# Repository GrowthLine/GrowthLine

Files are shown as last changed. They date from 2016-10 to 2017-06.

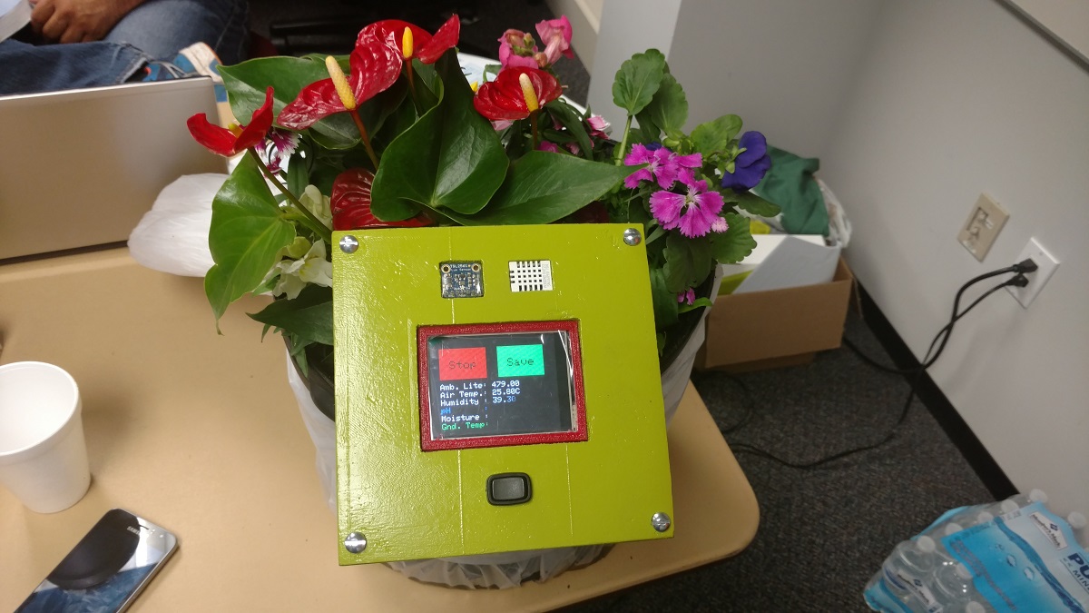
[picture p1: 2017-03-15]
web/img/testplant.jpg

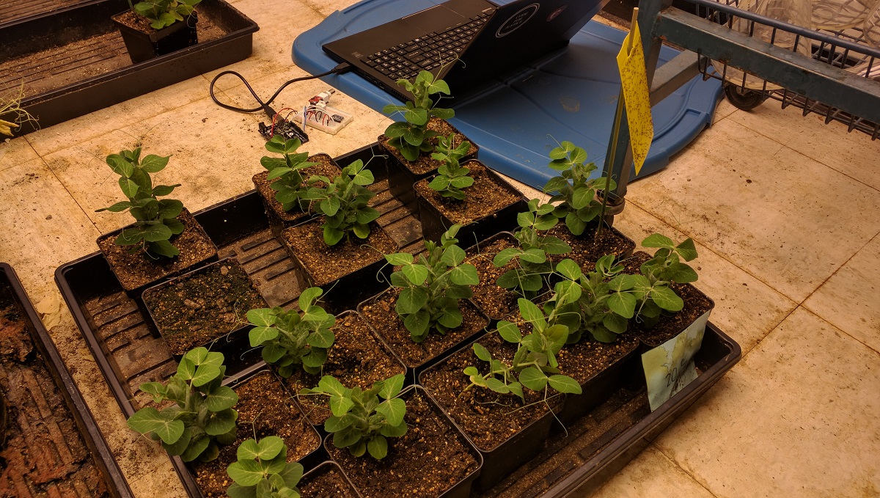
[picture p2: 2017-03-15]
web/img/data.jpg

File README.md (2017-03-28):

# GrowthLine
Growth Line Project

The GrowthLine directory contains the main code for the project itself. The TestFiles and Libraries directory contains test files and the libraries needed for the specific components used within the project.

Contributors: Henok Gezaw, Andrew Leverkuhn, Miguel Rosales, Jose Daniel Velazco, Daniel Weaver

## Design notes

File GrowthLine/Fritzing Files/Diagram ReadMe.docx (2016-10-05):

Diagram Information

- Created with Fritzing
  - Version 0.9.3b
  - Open source software that supports creation of electronics projects
  - Allows you to plan, document, and prepare project for production
  - Components for project are wired on a virtual breadboard
- Bread Board configuration
  - Centered around Arduino uno
  - The display(TFT Capacitive) and the lux sensor(TSL2561) both share serial clock(SCL) and serial data pins (SDA)
    - These two modules are communicated using the I²C (IIC) protocol
    - Multiple devices can be communicated to using only 2 pins
      - Varies based on micro controller
      - Analog pins 4 and 5 for Arduino uno
      - Each device has unique address to identify it in the line
    - I²C using series of rising and falling edges to signal
      - Start communication
      - End communication
      - Sending data to device
      - Read data from device
  - All modules share a common ground
  - The screen and lux sensor both use 3.3 volts
  - The remaining modules use 5v
  - There are 3 digital pins and 4 analog pins not being used
    - Possible future expansion
  - pH module (pH circuit) uses 2 pins
    - digital pins 3 and 4
    - can operate in I²C mode to allow for future expansion
    - isolation board not shown in this model (doesn’t affect wiring)
  - Air temperature and humidity (DHT11)
    - Uses 1 pin to transmit data for both readings
    - Digital pin 5
  - Display (TFT capactive)
    - Digital pins 9-13 for display control
    - Digital pin 4 to control the sdcard
    - Analog pins 4 and 5 used to read touch screen
      - SDA and SCL
  - Lux sensor (TSL2561)
    - Analog pins 4 and 5
      - SDA and SCL
  - Soil moisture and temperature (SHT10)
    - Digital pin 6 for data
    - Digital pin 7 for clock (bit that powers the logic)
  - Wiring has to be done manually at this stage
- Schematic
  - Simplifies the connection by merging
    - Common grounds
    - Common power lines
    - Removing the breadboard for direct connections
  - Same info as above (breadboard layout)
  - Modules represented by bloacks
  - Connections represented by a solid black line or a colored dashed line
  - Wiring automated by fritzing
- PCB (optional)
  - Fritzing can generate a PCB design based on your wiring
  - Design can be sent to fabricator for manufacturing
  - Wiring is automated by fritzing

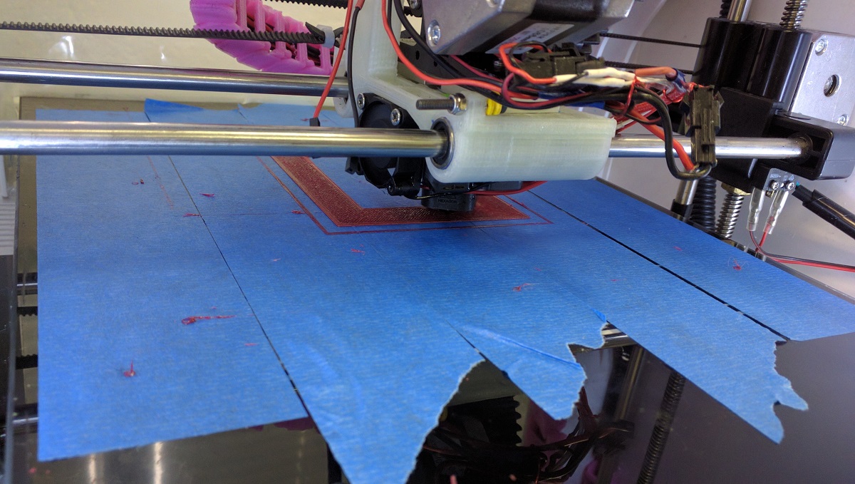
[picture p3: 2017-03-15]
web/img/3DPrint.jpg

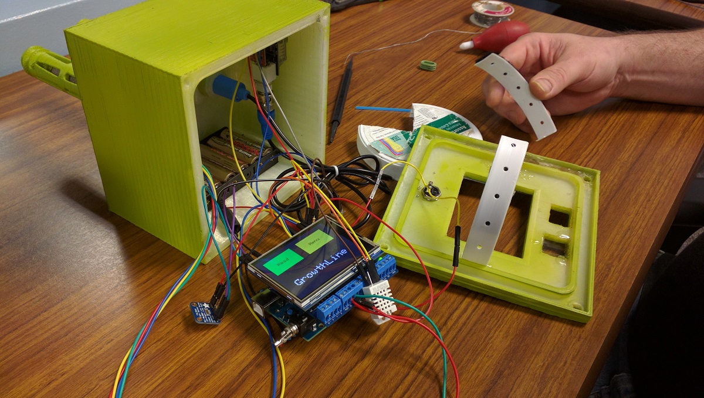
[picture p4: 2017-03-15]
web/img/Inside.jpg

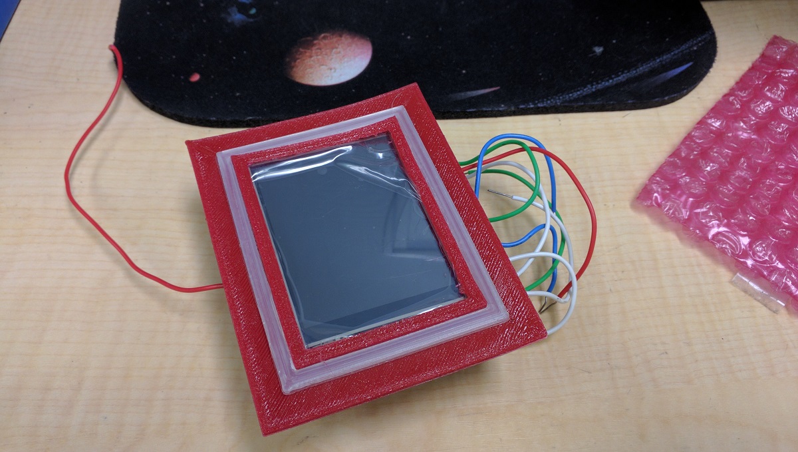
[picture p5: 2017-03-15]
web/img/Gasket.jpg

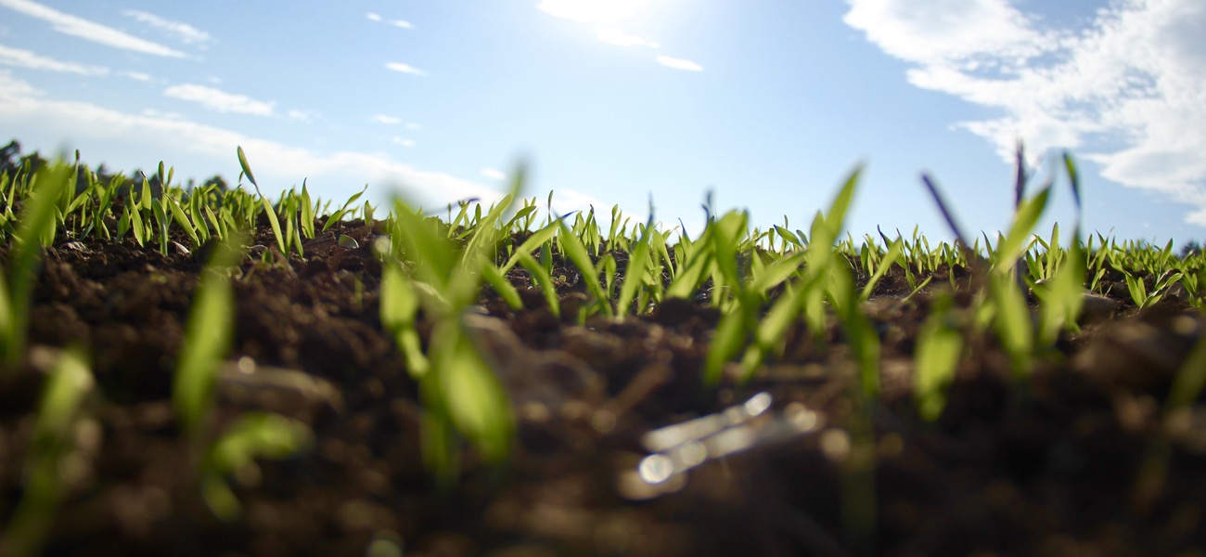
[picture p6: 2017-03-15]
web/img/growth.jpg

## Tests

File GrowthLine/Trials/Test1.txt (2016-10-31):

Reading 1

Setup is complete
The lux is: 11074.00
The air temperature is: 25.30
The humidity is: 47.90
The pH is: 2.32

The lux is: 11024.00
The air temperature is: 25.40
The humidity is: 46.60
The pH is: 2.09

The lux is: 11055.00
The air temperature is: 25.50
The humidity is: 46.20
The pH is: 0.00

The lux is: 11272.00
The air temperature is: 25.60
The humidity is: 45.90
The pH is: 1.91

The lux is: 11295.00
The air temperature is: 25.60
The humidity is: 46.00
The pH is: 1.70

The lux is: 11402.00
The air temperature is: 25.60
The humidity is: 46.00
The pH is: 1.47

The lux is: 11257.00
The air temperature is: 25.70
The humidity is: 45.70
The pH is: 1.25

The lux is: 11433.00
The air temperature is: 25.80
The humidity is: 45.40
The pH is: 1.02

The lux is: 11438.00
The air temperature is: 25.80
The humidity is: 45.20
The pH is: 0.85

The lux is: 11464.00
The air temperature is: 25.90
The humidity is: 45.10
The pH is: 0.00

The lux is: 11472.00
The air temperature is: 25.90
The humidity is: 44.80
The pH is: 0.69

The lux is: 11410.00
The air temperature is: 26.00
The humidity is: 44.70
The pH is: 0.47

The lux is: 11415.00
The air temperature is: 26.00
The humidity is: 44.60
The pH is: 0.25

The lux is: 11466.00
The air temperature is: 26.00
The humidity is: 44.40
The pH is: 0.00

The lux is: 11473.00
The air temperature is: 26.10
The humidity is: 44.30
The pH is: 0.00

The lux is: 11425.00
The air temperature is: 26.10
The humidity is: 44.30
The pH is: 0.00

The lux is: 11476.00
The air temperature is: 26.20
The humidity is: 44.20
The pH is: 0.00

The lux is: 11490.00
The air temperature is: 26.20
The humidity is: 44.10
The pH is: 0.00

The lux is: 11481.00
The air temperature is: 26.30
The humidity is: 43.90
The pH is: 0.00

The lux is: 11477.00
The air temperature is: 26.30
The humidity is: 43.90
The pH is: 0.00

The lux is: 11497.00
The air temperature is: 26.30
The humidity is: 43.80
The pH is: 0.00

The lux is: 11489.00
The air temperature is: 26.40
The humidity is: 43.70
The pH is: 0.00

The lux is: 11474.00
The air temperature is: 26.50
The humidity is: 43.50
The pH is: 0.00

The lux is: 11485.00
The air temperature is: 26.50
The humidity is: 43.30
The pH is: 0.00

The lux is: 11244.00
The air temperature is: 26.50
The humidity is: 43.20
The pH is: 0.00

The lux is: 11227.00
The air temperature is: 26.60
The humidity is: 43.20
The pH is: 0.00

The lux is: 11449.00
The air temperature is: 26.70
The humidity is: 43.10
The pH is: 0.00

The lux is: 11453.00
The air temperature is: 26.70
The humidity is: 43.00
The pH is: 0.00

The lux is: 11448.00
The air temperature is: 26.70
The humidity is: 43.20
The pH is: 0.00

The lux is: 11431.00
The air temperature is: 26.70
The humidity is: 43.10
The pH is: 0.00

The lux is: 11411.00
The air temperature is: 26.80
The humidity is: 43.00
The pH is: 0.00

The lux is: 11415.00
The air temperature is: 26.90
The humidity is: 42.70
The pH is: 0.00

The lux is: 11455.00
The air temperature is: 26.90
The humidity is: 42.50
The pH is: 0.00

The lux is: 11441.00
The air temperature is: 27.00
The humidity is: 42.30
The pH is: 0.00

The lux is: 11450.00
The air temperature is: 27.00
The humidity is: 42.20
The pH is: 0.00

The lux is: 11441.00
The air temperature is: 27.00
The humidity is: 42.10
The pH is: 0.00

The lux is: 11436.00
The air temperature is: 27.10
The humidity is: 41.90
The pH is: 0.00

The lux is: 11441.00
The air temperature is: 27.10
The humidity is: 42.00
The pH is: 0.00

The lux is: 11439.00
The air temperature is: 27.20
The humidity is: 41.80
The pH is: 0.00

The lux is: 11375.00
The air temperature is: 27.20
The humidity is: 41.70
The pH is: 0.00

The lux is: 11424.00
The air temperature is: 27.20
The humidity is: 41.60
The pH is: 0.00

The lux is: 11151.00
The air temperature is: 27.30
The humidity is: 41.50
The pH is: 0.00

The lux is: 11203.00
The air temperature is: 27.30
The humidity is: 41.40
The pH is: 0.00

The lux is: 11229.00
The air temperature is: 27.30
The humidity is: 41.50
The pH is: 0.00

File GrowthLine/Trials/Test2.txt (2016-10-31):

Reading 2 - More Inside

Setup is complete
The lux is: 11946.00
The air temperature is: 28.20
The humidity is: 39.70
The pH is: 0.00

The lux is: 12041.00
The air temperature is: 28.70
The humidity is: 38.40
The pH is: 0.00

The lux is: 12074.00
The air temperature is: 28.70
The humidity is: 38.30
The pH is: 0.00

The lux is: 12079.00
The air temperature is: 28.60
The humidity is: 38.20
The pH is: 0.00

The lux is: 12077.00
The air temperature is: 28.70
The humidity is: 38.10
The pH is: 0.00

The lux is: 12061.00
The air temperature is: 28.70
The humidity is: 38.00
The pH is: 0.00

The lux is: 12096.00
The air temperature is: 28.70
The humidity is: 38.00
The pH is: 0.00

The lux is: 12096.00
The air temperature is: 28.80
The humidity is: 38.00
The pH is: 0.00

The lux is: 12103.00
The air temperature is: 28.80
The humidity is: 38.00
The pH is: 0.00

The lux is: 12088.00
The air temperature is: 28.80
The humidity is: 38.10
The pH is: 0.00

The lux is: 12107.00
The air temperature is: 28.80
The humidity is: 38.00
The pH is: 0.00

The lux is: 12102.00
The air temperature is: 28.80
The humidity is: 37.90
The pH is: 0.00

The lux is: 12102.00
The air temperature is: 28.90
The humidity is: 37.90
The pH is: 0.00

The lux is: 12103.00
The air temperature is: 28.90
The humidity is: 37.80
The pH is: 0.00

The lux is: 12106.00
The air temperature is: 28.90
The humidity is: 37.80
The pH is: 0.00

The lux is: 12118.00
The air temperature is: 28.90
The humidity is: 37.80
The pH is: 0.00

The lux is: 12099.00
The air temperature is: 29.00
The humidity is: 37.80
The pH is: 0.00

The lux is: 12073.00
The air temperature is: 28.90
The humidity is: 37.80
The pH is: 0.00

The lux is: 12096.00
The air temperature is: 29.00
The humidity is: 37.80
The pH is: 0.00

The lux is: 12109.00
The air temperature is: 29.00
The humidity is: 37.80
The pH is: 0.00

The lux is: 12117.00
The air temperature is: 29.00
The humidity is: 37.80
The pH is: 0.00

The lux is: 12054.00
The air temperature is: 29.10
The humidity is: 37.70
The pH is: 0.00

The lux is: 12117.00
The air temperature is: 29.10
The humidity is: 37.70
The pH is: 0.00

The lux is: 12117.00
The air temperature is: 29.10
The humidity is: 37.60
The pH is: 0.00

The lux is: 12094.00
The air temperature is: 29.10
The humidity is: 37.50
The pH is: 0.00

The lux is: 12094.00
The air temperature is: 29.20
The humidity is: 37.30
The pH is: 0.00

The lux is: 12127.00
The air temperature is: 29.20
The humidity is: 37.30
The pH is: 0.00

The lux is: 12133.00
The air temperature is: 29.20
The humidity is: 37.30
The pH is: 0.00

The lux is: 12111.00
The air temperature is: 29.20
The humidity is: 37.20
The pH is: 0.00

The lux is: 12111.00
The air temperature is: 29.20
The humidity is: 37.10
The pH is: 0.00

The lux is: 12112.00
The air temperature is: 29.30
The humidity is: 37.10
The pH is: 0.00

The lux is: 12110.00
The air temperature is: 29.30
The humidity is: 37.20
The pH is: 0.00

The lux is: 12134.00
The air temperature is: 29.30
The humidity is: 37.20
The pH is: 0.00

The lux is: 12140.00
The air temperature is: 29.30
The humidity is: 37.10
The pH is: 0.00

The lux is: 12138.00
The air temperature is: 29.30
The humidity is: 37.20
The pH is: 0.00

The lux is: 12140.00
The air temperature is: 29.30
The humidity is: 37.20
The pH is: 0.00

The lux is: 12137.00
The air temperature is: 29.30
The humidity is: 37.10
The pH is: 0.00

The lux is: 12126.00
The air temperature is: 29.30
The humidity is: 37.00
The pH is: 0.00

The lux is: 12126.00
The air temperature is: 29.40
The humidity is: 37.00
The pH is: 0.00

The lux is: 12092.00
The air temperature is: 29.40
The humidity is: 37.00
The pH is: 0.00

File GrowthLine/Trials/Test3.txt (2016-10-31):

Reading 3 - Inside plant box

Setup is complete
The lux is: 12002.00
The air temperature is: 29.50
The humidity is: 36.60
The pH is: 0.00

The lux is: 10934.00
The air temperature is: 29.50
The humidity is: 36.60
The pH is: 0.00

The lux is: 11041.00
The air temperature is: 29.50
The humidity is: 37.70
The pH is: 0.00

The lux is: 11237.00
The air temperature is: 29.50
The humidity is: 37.30
The pH is: 0.00

The lux is: 11248.00
The air temperature is: 29.50
The humidity is: 37.00
The pH is: 0.00

The lux is: 11215.00
The air temperature is: 29.50
The humidity is: 36.70
The pH is: 0.00

The lux is: 11215.00
The air temperature is: 29.50
The humidity is: 36.70
The pH is: 0.00

The lux is: 11213.00
The air temperature is: 29.50
The humidity is: 36.70
The pH is: 0.00

The lux is: 11216.00
The air temperature is: 29.50
The humidity is: 36.60
The pH is: 0.00

The lux is: 11233.00
The air temperature is: 29.50
The humidity is: 36.80
The pH is: 0.00

The lux is: 11228.00
The air temperature is: 29.50
The humidity is: 36.90
The pH is: 0.00

The lux is: 11210.00
The air temperature is: 29.50
The humidity is: 36.80
The pH is: 0.00

The lux is: 11210.00
The air temperature is: 29.50
The humidity is: 36.80
The pH is: 0.00

The lux is: 11162.00
The air temperature is: 29.50
The humidity is: 36.70
The pH is: 0.00

The lux is: 11198.00
The air temperature is: 29.40
The humidity is: 36.70
The pH is: 0.00

The lux is: 11122.00
The air temperature is: 29.40
The humidity is: 36.80
The pH is: 0.00

The lux is: 11122.00
The air temperature is: 29.40
The humidity is: 36.90
The pH is: 0.00

The lux is: 11116.00
The air temperature is: 29.40
The humidity is: 36.80
The pH is: 0.00

The lux is: 11111.00
The air temperature is: 29.40
The humidity is: 36.60
The pH is: 0.00

The lux is: 11116.00
The air temperature is: 29.40
The humidity is: 36.50
The pH is: 0.00

The lux is: 11219.00
The air temperature is: 29.40
The humidity is: 36.50
The pH is: 0.00

The lux is: 11172.00
The air temperature is: 29.40
The humidity is: 36.50
The pH is: 0.00

The lux is: 11253.00
The air temperature is: 29.40
The humidity is: 36.70
The pH is: 0.00

The lux is: 11260.00
The air temperature is: 29.40
The humidity is: 36.70
The pH is: 0.00

The lux is: 11254.00
The air temperature is: 29.40
The humidity is: 36.70
The pH is: 0.00

The lux is: 11249.00
The air temperature is: 29.40
The humidity is: 36.80
The pH is: 0.00

The lux is: 11246.00
The air temperature is: 29.40
The humidity is: 36.80
The pH is: 0.00

The lux is: 11246.00
The air temperature is: 29.40
The humidity is: 36.90
The pH is: 0.00

The lux is: 11242.00
The air temperature is: 29.40
The humidity is: 36.90
The pH is: 0.00

The lux is: 11235.00
The air temperature is: 29.40
The humidity is: 36.90
The pH is: 0.00

The lux is: 11227.00
The air temperature is: 29.40
The humidity is: 36.80
The pH is: 0.00

The lux is: 11222.00
The air temperature is: 29.40
The humidity is: 36.90
The pH is: 0.00

The lux is: 11219.00
The air temperature is: 29.40
The humidity is: 37.10
The pH is: 0.00

The lux is: 11218.00
The air temperature is: 29.40
The humidity is: 37.00
The pH is: 0.00

The lux is: 11222.00
The air temperature is: 29.30
The humidity is: 36.90
The pH is: 0.00

The lux is: 11224.00
The air temperature is: 29.40
The humidity is: 36.80
The pH is: 0.00

The lux is: 11227.00
The air temperature is: 29.30
The humidity is: 37.00
The pH is: 0.00

The lux is: 11230.00
The air temperature is: 29.30
The humidity is: 37.00
The pH is: 0.00

The lux is: 11229.00
The air temperature is: 29.30
The humidity is: 36.90
The pH is: 0.00

The lux is: 11206.00
The air temperature is: 29.30
The humidity is: 36.90
The pH is: 0.00

The lux is: 11210.00
The air temperature is: 29.30
The humidity is: 36.90
The pH is: 0.00

The lux is: 11209.00
The air temperature is: 29.30
The humidity is: 36.90
The pH is: 0.00

The lux is: 11232.00
The air temperature is: 29.30
The humidity is: 37.00
The pH is: 0.00

The lux is: 11229.00
The air temperature is: 29.30
The humidity is: 37.00
The pH is: 0.00

The lux is: 11196.00
The air temperature is: 29.30
The humidity is: 37.00
The pH is: 0.00

The lux is: 11220.00
The air temperature is: 29.30
The humidity is: 36.90
The pH is: 0.00

The lux is: 11210.00
The air temperature is: 29.30
The humidity is: 36.90
The pH is: 0.00

The lux is: 10985.00
The air temperature is: 29.30
The humidity is: 37.00
The pH is: 0.00

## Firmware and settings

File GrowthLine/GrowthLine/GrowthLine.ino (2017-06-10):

#include "lib.h"

/* Variable Declarations */
List<Reading> readings(5);           // List used to hold reading objects. Structured in a queue.
Sensors sensors;                                // Object that will hold and manage all other sensors
int deviceState;                                // State of device
bool fahrenheit;                                // Saves user information about temperature unit
bool redraw;                                    // Flag used to know when to redraw a screen
bool tempChange;                                // Flag used to ID when to redraw Temp buttons
unsigned long milliseconds;                     // saves milliseconds. Used with millis() to check lenths of time
unsigned int currentRead;                       // holds a value of the latest read displayed on the log screen
String statusBar;                               // holds the message displayed on the status bar
Adafruit_STMPE610 *ts;                          // pointer to a touch screen object
Adafruit_ILI9341 *tft;                          // pointer to a display object
int tempReadingNumber;
Reading tempReading;

void setup() {
  Serial.begin(9600);
  Serial.println("Software Initializing");
  tft = new Adafruit_ILI9341(TFT_CS, TFT_DC);
  tft->begin();
  tft->setRotation(1);
  draw_Startup();
  deviceState   = READY_STATE;
  redraw        = true;
  fahrenheit    = false;
  tempChange    = true;
  currentRead   = 1;
  statusBar     = "GrowthLine";
  String logNumberBuffer = "";                     // holds the settings from the buffer
  String lineReadBuffer = "";

  /* Add the sensors to our Sensors object */
  LightSensor* lightSensor = new LightSensor();
  sensors.addSensor(lightSensor);
  TempHumid* tempHumid = new TempHumid(TEMP_HUMID_PIN);
  sensors.addSensor(tempHumid);
  pH* ph = new pH(PH_RECEIVE_PIN, PH_TRANSMIT_PIN);
  sensors.addSensor(ph);
  TempMoist* tempMoist = new TempMoist(TEMP_MOIST_DATA_PIN, TEMP_MOIST_CLOCK_PIN);
  sensors.addSensor(tempMoist);

  /* Create our touch objects */
  ts = new Adafruit_STMPE610(STMPE_CS);

  /* Setup the sensors */
  sensors.setupSensors();

  /* Setting up the SD card */
  if (! SD.begin(SD_CS_PIN)) {
    Serial.println("SD card initialization failed!");
  }
  else {
    Logger::saveEnable = false;
    // If the settings file is missing, make it with the defaults
    if ( !SD.exists("settings.txt")) {
      Serial.println("Making Settings File");
      File settingsFile = SD.open("settings.txt", FILE_WRITE);
      settingsFile.println("TempUnit=C");
      settingsFile.println("LogFile=1");
      settingsFile.println("Reading=1");
      settingsFile.close();
    }
    File settingsFile = SD.open("settings.txt");
    while (settingsFile.available() && (char)settingsFile.read() != '=');               // find the first = sign, which indicates temp. unit
    if (settingsFile.available() && (char)settingsFile.read() == 'F')
      fahrenheit = true;
    while (settingsFile.available() && (char)settingsFile.read() != '=');
    while (settingsFile.available() && (char)settingsFile.peek() != '\n') {
      logNumberBuffer += (char)settingsFile.read();
    }
    while (settingsFile.available() && (char)settingsFile.read() != '=');
    while (settingsFile.available() && (char)settingsFile.peek() != '\n') {
      lineReadBuffer += (char)settingsFile.read();
    }
    if (logNumberBuffer.toInt() != 0) {
      Logger::logFileNumber = logNumberBuffer.toInt();
    }
    else {
      Logger::logFileNumber = 1;
    }
    if (lineReadBuffer.toInt() != 0) {
      Logger::readingNumber = lineReadBuffer.toInt();
    }
    else {
      Logger::readingNumber = 1;
    }
    settingsFile.close();
    Logger::checkLogExists();
  }
  /* check that touch screen is started propperly */
  while (true) {
    if (ts->begin()) {
      break;
    } else {
      Serial.println("Touchscreen controller start failure!");
    }
  }
  Serial.println("Setup is complete");
}

/*
   The if (redraw) prevents the entire screen from
   being redrawn every loop() cycle. This prevents
   flickering.
*/
void loop() {
  // Determine if the screen was touched and on which quadrant
  TS_Point touchedPoint;
  uint8_t touchedQuadrant = BTN_NONE;
  while (ts->touched()) {
    touchedPoint = ts->getPoint();
    if ( touchedPoint.z < 75 )
      touchedQuadrant = getQuadrantFromPoint(&touchedPoint);
  }

  // State Machine of the device
  switch (deviceState) {
    case READY_STATE:
      if (redraw) {
        Serial.println("device is ready");
        draw_MainMenu();
        redraw = false;
      }
      switch (touchedQuadrant) {
        case BTN_NE:
          deviceState = MENU_STATE;
          redraw = true;
          break;
        case BTN_NW:
          deviceState = WARMUP_STATE;
          redraw = true;
          break;
      }
      break;
    case WARMUP_STATE:
      if (redraw) {
        draw_WarmUpScreen();
        redraw = false;
      }
      milliseconds = millis();
      for ( int i = 0; i < 5; i++ ) {                       // get initial 5 readings
        readings.add( sensors.getReading() );
        while (millis() - milliseconds < READING_FREQUENCY);
        milliseconds = millis();
      }

      while (!stableReadings(readings)) {
        milliseconds = millis();
        while ( millis() - milliseconds < READING_FREQUENCY);
        readings.add( sensors.getReading() );
      }
      deviceState = READ_STATE;
      redraw = true;
      break;
    case READ_STATE:
      if (redraw) {
        draw_ReadScreen();
        redraw = false;
      }
      switch (touchedQuadrant) {
        case BTN_NE:
          if (Logger::saveEnable) {             // if save button is pressed, save and go back to main menu
            deviceState = SAVE_STATE;
            redraw = true;
          }
          break;
        case BTN_NW:                   // if stop button is pressed, do not save and go back to main menu
          deviceState = READY_STATE;
          redraw = true;
          statusBar = "GrowthLine";
          readings.clear();
          break;
      }
      if ( millis() - milliseconds > READING_FREQUENCY) {   // updates displayed reading
        readings.add( sensors.getReading() );
        milliseconds = millis();
        update_Readings();
      }
      break;
    case SAVE_STATE:
      if (redraw) {
        draw_SaveScreen();
        redraw = false;
      }
      Serial.println("Saving log file");
      tempReading = readings.get_new();
      Logger::saveLog(tempReading, fahrenheit);
      Serial.println("Log saved");
      deviceState = READY_STATE;
      redraw = true;
      statusBar = "Read Saved";
      readings.clear();
      Logger::saveSettings(fahrenheit);
      Serial.println("Entering READY_STATE");
      break;
    case MENU_STATE:
      if (redraw) {
        draw_MenuScreen();
        redraw = false;
      }
      switch (touchedQuadrant) {
        case BTN_NE:
          deviceState = SETTINGS_STATE;
          redraw = true;
          break;
        case BTN_NW:
          deviceState = READY_STATE;
          redraw = true;
          statusBar = "GrowthLine";
          break;
        case BTN_SW:
          if ( Logger::saveEnable ) {
            deviceState = LOG_STATE;
            redraw = true;
          }
          break;
        case BTN_SE:
          deviceState = SHUTDOWN_STATE;
          redraw = true;
          break;
      }
      break;
    case SETTINGS_STATE:
      if (redraw) {
        draw_SettingsScreen();
        redraw = false;
      }
      if (tempChange) {
        draw_TempButtons();
        tempChange = false;
      }
      switch (touchedQuadrant) {
        case BTN_NE:
          if ( fahrenheit ) {
            fahrenheit = false;
          } else {
            fahrenheit = true;
          }
          Logger::saveSettings(fahrenheit);
          tempChange = true;
          break;
        case BTN_NW:
          deviceState = MENU_STATE;
          redraw = true;
          break;
        case BTN_SW:
          deviceState = CALIBRATE_STATE;
          redraw = true;
          break;
        case BTN_SE:
          if (Logger::saveEnable) {
            Logger::logFileNumber += 1;
            Logger::checkLogExists();
            Logger::readingNumber = 1;
            Logger::saveSettings(fahrenheit);
            deviceState = READY_STATE;
            redraw = true;
            statusBar = "NewLogFile";
          }
          break;
      }
      break;
    case CALIBRATE_STATE:
      if (redraw) {
        draw_CalibrateScreen();
        redraw = false;
      }
      if (touchedQuadrant == BTN_NW) {                      // if stop button is pressed, do not save and go back to menu
        deviceState = MENU_STATE;
        redraw = true;
      }
      else if ( touchedQuadrant == BTN_NE) {                // if go button is pressed, calibrate pH sensor
        pH* phSensor = (pH*)sensors.getSensor(PH_SENSOR_ID);
        phSensor->calibrate();
        deviceState = READY_STATE;
        redraw = true;
        statusBar = "Calibrated";
      }
      break;
    case LOG_STATE:
      if (redraw) {
        String logs[5] = {"", "", "", "", ""};
        Logger::getLogs(String("log") + Logger::logFileNumber + ".txt", logs, &currentRead);
        draw_LogScreen(logs);
        redraw = false;
      }
      if ( touchedQuadrant == BTN_NW) {
        deviceState = MENU_STATE;
        currentRead = 1;
        redraw = true;
      }
      else if ( touchedQuadrant == BTN_NE) {
        String logs[5] = {"", "", "", "", ""};
        Logger::getLogs(String("log") + Logger::logFileNumber + ".txt", logs, &currentRead);
        update_Logs(logs);
        if (currentRead >= Logger::readingNumber)
          currentRead = 1;
      }
      break;
    case SHUTDOWN_STATE:      // ******** Need to do this one ******* ///
      if (redraw) {
        draw_ShutdownScreen();
        redraw = false;
      }
      break;
    default:
      break;
  }
}

/* Display Functions */
void draw_MainMenu() {
  // Blank screen
  tft->fillScreen(ILI9341_BLACK);

  /* Set text attributes */
  tft->setTextSize(2);

  /* Draw NW 'Read' button */
  tft->fillRect( 20, 20, 120, 80, ILI9341_GREEN );
  tft->setCursor( 55, 52);
  tft->setTextColor( ILI9341_BLACK, ILI9341_GREEN );
  tft->println("Read");

  /* Draw NE 'Menu' button */
  tft->fillRect(170, 20, 120, 80, ILI9341_YELLOW);
  tft->setCursor(205, 52);
  tft->setTextColor( ILI9341_BLACK, ILI9341_YELLOW);
  tft->println("Menu");

  /* Draw 'GrowthLine' text logo */
  tft->setTextSize(4);
  tft->setTextColor( ILI9341_WHITE, ILI9341_BLACK);
  tft->setCursor(35, 162);
  tft->println(statusBar);
}

void draw_WarmUpScreen() {
  /* Blank screen */
  tft->fillScreen(ILI9341_BLACK);

  /* Set text attributes and draw text */
  tft->setTextSize(3);
  tft->setCursor( 70, 100);
  tft->setTextColor( ILI9341_WHITE, ILI9341_BLACK);
  tft->println("Warming up");
}

void draw_SaveScreen() {
  /* Blank screen */
  tft->fillScreen(ILI9341_BLACK);

  /* Set text attributes and draw text. */
  tft->setTextSize(3);
  tft->setCursor( 82, 100);
  tft->setTextColor( ILI9341_WHITE, ILI9341_BLACK);
  tft->println("Saving");
}

void draw_Startup() {
  /* Blank screen */
  tft->fillScreen(ILI9341_BLACK);

  /* Set text attributes and draw text. */
  tft->setTextSize(3);
  tft->setCursor( 30, 100);
  tft->setTextColor( ILI9341_WHITE, ILI9341_BLACK);
  tft->println("  Initializing  ");
}

void draw_ShutdownScreen() {
  /* Blank screen */
  tft->fillScreen(ILI9341_BLACK);

  /* Set text attributes and draw text. */
  tft->setTextSize(3);
  tft->setCursor( 30, 100);
  tft->setTextColor( ILI9341_WHITE, ILI9341_BLACK);
  tft->println("Safe to Shutdown");
}

void draw_ReadScreen() {
  // Blank the screen
  tft->fillScreen(ILI9341_BLACK);

  // Set text parameters
  tft->setTextSize(3);

  // Draw NW 'Stop' button
  tft->fillRect( 20, 20, 120, 80, ILI9341_RED);
  tft->setCursor( 45, 52);
  tft->setTextColor( ILI9341_BLACK, ILI9341_RED);
  tft->println("Stop");

  // Draw NE 'Save' button
  tft->fillRect(170, 20, 120, 80, ILI9341_GREEN);
  tft->setCursor(195, 52);
  tft->setTextColor( ILI9341_BLACK, ILI9341_GREEN);
  tft->println("Save");
}

void update_Readings() {
  /* Blank out numbers */
  tft->fillRect(140, 101, 180, 139, ILI9341_BLACK);

  /* Set text parameters */
  tft->setTextSize(2);
  tft->setTextColor( ILI9341_WHITE, ILI9341_BLACK);

  /* Draw reading 1 - Ambient Light */
  String amb_lite    = "Amb. Lite: ";
  tft->setCursor( 20, 112);
  tft->println(amb_lite + readings.get_new().getReadValueByType(ReadType::LUX));

  /* Draw reading 2 - Air Temperature */
  String air_temp    = "Air Temp.: ";
  tft->setCursor( 20, 132);
  if (fahrenheit) {
    tft->println(air_temp + cToF(readings.get_new().getReadValueByType(ReadType::AIR_TEMP)) + "F");
  } else {
    tft->println(air_temp + readings.get_new().getReadValueByType(ReadType::AIR_TEMP) + "C");
  }

  /* Draw reading 3 - Humidity */
  String humidity    = "Humidity : ";
  tft->setCursor( 20, 152);
  tft->println(humidity + readings.get_new().getReadValueByType(ReadType::HUMIDITY));

  /* Draw reading 4 - Soil pH */
  switch (phStatus(readings.get_new().getReadValueByType(ReadType::PH))) {
    case BAD_LOW:
      tft->setTextColor( ILI9341_BLUE, ILI9341_BLACK);
      break;
    case GOOD:
      tft->setTextColor( ILI9341_GREEN, ILI9341_BLACK);
      break;
    case BAD_HIGH:
      tft->setTextColor( ILI9341_RED, ILI9341_BLACK);
      break;
    default:
      break;
  }
  String ph          = "pH       : ";
  tft->setCursor( 20, 172);
  tft->println(ph + readings.get_new().getReadValueByType(ReadType::PH));

  /* Draw reading 5 - Soil moisture  */
  tft->setTextColor( ILI9341_WHITE, ILI9341_BLACK);
  String moisture    = "Moisture : ";
  tft->setCursor( 20, 192);
  tft->println(moisture + readings.get_new().getReadValueByType(ReadType::MOISTURE));

  /* Draw rea
    ding 6 - Ground temperature */
  switch (groundTempStatus(readings.get_new().getReadValueByType(ReadType::GROUND_TEMP))) {
    case BAD_LOW:
      tft->setTextColor( ILI9341_BLUE, ILI9341_BLACK);
      break;
    case GOOD:
      tft->setTextColor( ILI9341_GREEN, ILI9341_BLACK);
      break;
    case BAD_HIGH:
      tft->setTextColor( ILI9341_RED, ILI9341_BLACK);
      break;
    default:
      break;
  }
  String ground_temp = "Gnd. Temp: ";
  tft->setCursor( 20, 212);
  if (fahrenheit) {
    tft->println(ground_temp + cToF(readings.get_new().getReadValueByType(ReadType::GROUND_TEMP)) + "F");
  } else {
    tft->println(ground_temp + readings.get_new().getReadValueByType(ReadType::GROUND_TEMP) + "C");
  }
}

void draw_CalibrateScreen() {
  /* Blank the screen */
  tft->fillScreen(ILI9341_BLACK);

  /* Set text attributes */
  tft->setTextSize(3);

  /* Draw NW 'Back' button */
  tft->fillRect( 20, 20, 120, 80, ILI9341_RED);
  tft->setCursor( 45, 52);
  tft->setTextColor( ILI9341_BLACK, ILI9341_RED);
  tft->println("Back");

  /* Draw NE 'Go' button */
  tft->fillRect(170, 20, 120, 80, ILI9341_GREEN);
  tft->setCursor(215, 52);
  tft->setTextColor( ILI9341_BLACK, ILI9341_GREEN);
  tft->println("Go");

  /* Set text attributes and draw instructions */
  tft->setTextSize(2);
  tft->setTextColor( ILI9341_WHITE, ILI9341_BLACK);
  tft->setCursor( 20, 132); tft->print("Dip the pH probe into a");
  tft->setCursor( 20, 152); tft->print(" 7 pH solution at 25C." );
  tft->setCursor( 20, 172); tft->print(" After 2 min, press Go.");
  tft->setCursor( 20, 212); tft->print(" Press back to cancel." );
}

void draw_MenuScreen() {
  /* Blank screen */
  tft->fillScreen(ILI9341_BLACK);

  /* Set text attributes */
  tft->setTextSize(2);
  tft->setTextColor( ILI9341_BLACK, ILI9341_YELLOW );

  /* Draw NW 'Back' button */
  tft->fillRect( 20, 20, 120, 80, ILI9341_YELLOW );
  tft->setCursor( 55, 52);
  tft->println("Back");

  /* Draw NE 'Settings' button */
  tft->fillRect(180, 20, 120, 80, ILI9341_YELLOW);
  tft->setCursor(193, 52);
  tft->println("Settings");

  /* Set text color for following buttons */
  tft->setTextColor( ILI9341_BLACK, ILI9341_MAGENTA);

  /* Draw SW 'View Logs' button */
  tft->fillRect( 20, 140, 120, 80, ILI9341_MAGENTA);
  tft->setCursor( 25, 172);
  tft->println("View Logs");

  /* Draw SE 'Shut Down' button */
  tft->fillRect(180, 140, 120, 80, ILI9341_MAGENTA);
  tft->setCursor(185, 172);
  tft->println("Shut Down");
}

void draw_SettingsScreen() {
  tft->fillScreen(ILI9341_BLACK);
  // Draw boxes
  tft->fillRect( 20, 20, 120, 80, ILI9341_YELLOW );
  tft->fillRect( 20, 140, 120, 80, ILI9341_MAGENTA);
  tft->fillRect(180, 140, 120, 80, ILI9341_MAGENTA);
  tft->setTextSize(2);
  // Write text on button 1
  tft->setCursor( 55, 52);
  tft->setTextColor( ILI9341_BLACK, ILI9341_YELLOW );
  tft->println("Back");
  draw_TempButtons();
  // Set text color for following buttons
  tft->setTextColor( ILI9341_BLACK, ILI9341_MAGENTA);
  // Write text on button 3
  tft->setCursor( 27, 172);
  tft->println("Calibrate");
  // Write text on button 4
  tft->setCursor(200, 172);
  tft->println("New Log");
}

void draw_TempButtons() {
  // Write text on button 2
  if (fahrenheit) {
    tft->fillRect(180, 20, 60, 80, ILI9341_MAROON);
    tft->setTextColor( ILI9341_BLACK, ILI9341_MAROON);
    tft->setCursor(207, 52);
    tft->print("C");
    tft->fillRect(240, 20, 60, 80, ILI9341_GREEN);
    tft->setTextColor( ILI9341_BLACK, ILI9341_GREEN);
    tft->setCursor(267, 52);
    tft->print("F");
  } else {
    tft->fillRect(180, 20, 60, 80, ILI9341_GREEN);
    tft->setTextColor( ILI9341_BLACK, ILI9341_GREEN);
    tft->setCursor(207, 52);
    tft->print("C");
    tft->fillRect(240, 20, 60, 80, ILI9341_MAROON);
    tft->setTextColor( ILI9341_BLACK, ILI9341_MAROON);
    tft->setCursor(267, 52);
    tft->print("F");
  }
}

void draw_LogScreen(String in_array[]) {
  /* Blank the screen */
  tft->fillScreen(ILI9341_BLACK);

  /* Set text attributes */
  tft->setTextSize(3);

  /* Draw NW 'Back' button */
  tft->fillRect( 20, 20, 120, 80, ILI9341_RED);
  tft->setCursor( 45, 52);
  tft->setTextColor( ILI9341_BLACK, ILI9341_RED);
  tft->println("Back");

  /* Draw NE 'Next' button */
  tft->fillRect(170, 20, 120, 80, ILI9341_GREEN);
  tft->setCursor(195, 52);
  tft->setTextColor( ILI9341_BLACK, ILI9341_GREEN);
  tft->println("Next");

  /* Output headers */
  tft->setTextSize(2);
  tft->setTextColor( ILI9341_WHITE, ILI9341_BLACK);
  tft->setCursor( 20, 122);
  tft->println("# gT Moi pH aT Hum Lux");

  /* Output lines */
  for (int i = 0; i < 5; i++) {
    tft->setCursor( 20, 142 + (i * 20));
    tft->println(in_array[i]);
  }
}

void update_Logs(String in_array[]) {
  /* Blank out logs */
  tft->fillRect(10, 142, 300, 100, ILI9341_BLACK);

  /* Output lines */
  tft->setTextSize(2);
  tft->setTextColor( ILI9341_WHITE, ILI9341_BLACK);
  for (int i = 0; i < 5; i++) {
    tft->setCursor( 20, 142 + (i * 20));
    tft->println(in_array[i]);
  }
}

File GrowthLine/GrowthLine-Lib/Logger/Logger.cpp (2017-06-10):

#include "Logger.h"
#include <SD.h>

Logger::Logger() {}

bool Logger::saveEnable = false;
unsigned long Logger::logFileNumber = 1;
unsigned long Logger::readingNumber = 1;

void Logger::saveSettings(bool fahrenheit) {
    if (saveEnable) {
        SD.remove("settings.txt");
        File settingsFile = SD.open("settings.txt", FILE_WRITE);
        settingsFile.print("TempUnit");
        settingsFile.println(fahrenheit ? "F" : "C" );
        settingsFile.println("LogFile=" + String(logFileNumber));
        settingsFile.println("Reading=" + String(readingNumber));
        settingsFile.close();
        Serial.println("Settings Updated!");
    } else {
        Serial.println("Save was not enabled during setup");
    }
}

void Logger::saveLog(Reading& reading, const bool& fahrenheit) {
    String logFileName = "log" + String(logFileNumber) + ".txt";
    if (SD.exists(logFileName)) {
        File logFile = SD.open(logFileName, FILE_WRITE);
        logFile.println(String(readingNumber) + "," + reading.toStringSpecific(fahrenheit));
        logFile.close();
        readingNumber += 1;
    }
    else {
        Serial.println("Log File Not Found!");
    }
}

void Logger::checkLogExists()  {
    String logFileName = "log" + String(logFileNumber) + ".txt";
    String fileHeader = "Reading Number,Soil Temperature,Soil Moisture,Soil pH,Air Temperature,Air Humidity,Lux";
    if (!SD.exists(logFileName)) {
        File logFile = SD.open(logFileName, FILE_WRITE);
        logFile.println(fileHeader);
        logFile.close();
        Serial.println("New log file created " + logFileName);
    }
    else {
        Serial.println("Log File Found!");
    }
}

void Logger::getLogs(const String& fileName, String logs[], unsigned int *logNumber) {
    File logFile = SD.open(fileName);

    // Read data already displayed in the log scereen
    uint8_t logCounter = 0;
    while (logCounter != *logNumber && logFile.available() ) {
        if (logFile.read() == '\n')
        logCounter += 1 ;
    }

    if(!logFile.available()) {                             // if the file has been fully read, just exit
        logFile.close();
        return;
    }

    uint8_t index = 0;                                  // current array index
    bool use = true;                                    // used to tell whether we save character or not
    uint8_t commaCount = 0;                             // used to tell when we arrive to pH field
    while ( logFile.available() ) {
        if ( index == 5 )                                 // once we have 5 logs, exit
        break;
        char current = logFile.read();
        if ( current == '\n') {                           // we finished reading one record
        index += 1;
        commaCount = 0;
        use = true;
        continue;
        }
        if ( current == '.' && commaCount != 3) {         // truncate fractinoal part, except for pH
        use = false;
        continue;
        }
        else if ( current == ',') {                       // start saving characters again, for next fields
        commaCount += 1;
        use = true;
        }
        if ( use )                                        // concatinate the current character to the current log
        logs[index] += current;
    }
    logFile.close();
    *logNumber += index;
}

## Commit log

2016-09-30 Fritzing Files Added
    Added libraries, fritzing sketches, and diagrams for the Growth Line
    sensors.
    [Growthline 1_1.fzz]
2016-09-30 Updated Wiring
    [Growthline 1_1.fzz]
2016-09-30 Updated scematics and added PCB tracing
    [Growthline 1_1.fzz]
2016-10-16 Light Sensor Test File Added
    Created a directory to put our test files. I have included a file that
    tests the light sensor and the libraries required to make it work.
2016-10-16 Temp/Moist Sensor Test Files
    Included the test files for the Temp/Moist (SHT10) sensor.
2016-10-25 Added more test files and info files
    Added more test files for other sensors. Also, included an info file
    with extra info on the sensor being tested.
2016-10-26 Fixed Bugs Related to Header File
    Some things shouldn't be in the header file, so I moved to main program.
    Also, the display functions are not working.
    [GrowthLine.ino]
2016-10-26 Added the Temp/Humid sensor
    Tested the sensor and there's information about it on the info file in
    its test file directory.
2016-10-26 Added more Sensors
    Added more sensor information to the main file
2016-10-29 Added Sensor Classes
    I added some Sensor Classes for two different sensors (I still don't
    test one of them). I am still workign on these classes. Please try not
    to modify these while I am working on them.
2016-10-29 Added More Sensor Classes
    I still need to finish temperature/moisture sensor logic. But the
    skeleon is there.
2016-10-29 Array of Sensors
    Added an array that holds all the sensors, initializes and sets them up.
    We can use this array to read from all sensors in a 2 line for loop.
2016-10-29 Add some pin constants
2016-10-29 Added button constants
2016-10-29 Added button constants
    Also fleshed out warm up screen and added screen blanking commands.
2016-11-01 Added the Temp/Moisture Sensor
    All sensors are plugged in and working togethere now. This code now
    shows all the readings to the screen.
2016-11-05 Added a Sensors Class
    Several changes have been made:
    1. Added the Sensors class which will make it easier to use on the
    main file. It also setups for possibilities of adding more or different
    sensors for the future.
    2. There's also a spreadsheet with the anallysis of the last
    readgins in each trial we did in the Growth Lab.
    3. The DHT files are no longer in the main directory. You need to
    add the library to your arduino libraries folder. The library is in the
    TestFiles/TempHumid/ folder. Just add that zip file to your libraries
    and you shall get no errors.
    [Sample Reading Statistics.xlsx]
2016-11-06 Fixed PH Bad readings
    The PH sensor provides nothing but good readings now. Woots!
    [GrowthLine.ino]
2016-11-09 Fleshed out more screens
    Touch still does not work properly.
    [GrowthLine.ino]
2016-11-12 Staged changes to read screen
    Prepared draw_ReadScreen for reading printout code.
2016-11-16 Finished the UI
    Bugs may exist.
    [GrowthLine.ino]
2016-11-16 Removed unused button constants
2016-11-16 Adjusted a couple of functions
    Swapped position of draw_ReadScreen and update_Readings.
    Adjusted blanking rectangle in update_Readings to only blank out numeric portion of readings and to not extend beyond screen coordinates.
    Added comments.
    [GrowthLine.ino]
2016-11-17 Housekeeping and Button Presses
    Cleaned some of the code so it's more readable. I added code to several
    states button presses. Only states missing is Menu, Calibratoin, and
    Shut down.
    [GrowthLine.ino, lib.h]
2016-11-17 Calibrate Code is Up
    Calibrate code is added and adjusted to fit the screen's button presses
    on the calibration screen. Also, the menu screen has button press
    detection now.
2016-11-17 Change of temperature Added
    User can now select between Celcious and Fahrenheit. The button gets
    updated to show the letter of the selection.
2016-11-17 Initial framework for log output lines
2016-11-18 Updated code to work with Arduino 101
    We changed boards. The old DHT libraries are not compatible so we had to
    find a new library and there were some unknown errors we had to deal
    with. You'll need to download the Adafruit DHT_U and DHT library to make
    this work.
    [GrowthLine.ino, lib.h]
2016-11-18 Added new DHT library to the TempHumid test folder
    The new library works with the Arduino 101. Make sure you add it to your
    libraries.
2016-11-21 So Daniel doesn't have to merge repos.
    [GrowthLine.ino]
2016-11-21 Updated code to work with Arduino 101
    The reading object wasn't propperly returned and was not working with
    Arduino 101. The new code adjusts that and the readings are propperly
    displayed on the screen, woot!
    [GrowthLine.ino, lib.h]
2016-11-21 Added Status Bar
    The status bar now shows some messages to user depending on the actions
    taken. Also, the readings display of temperature now show C for celcious
    and F for fahrenheit.
2016-11-23 Added Reading Checks for Warmup State
    A new function checks the last 5 readings. This determines whether the
    readings obtained are accurate or if the sensors are still stabilizing.
    Do note this will get the Warm up screen stuck if the sensors are not
    plugged in. You must include the Statistics library included in the Test
    files and Libraries directory
    [GrowthLine.ino, lib.h]
2016-11-25 Fully functional code!
    This is a final working code. Further testing needs to be made once the
    device is fully assembled, woots!
2016-11-25 Fixed bugs with the SaveLog function
    [GrowthLine.ino, lib.h]
2016-11-25 Working Settings and User logs
    User settings are now appropriately saved and the log files are managed
    and read correctly.
    [GrowthLine.ino]
2016-11-26 Startup screen added
    A setup screen has ben added to let the user know the device is starting
    up and setting up the components.
2017-03-15 Added Page
    Added our own html page
    [Growthline 1_1.fzz, Sample Reading Statistics.xlsx]
2017-03-15 Changed Web Page
    Changed the Web Page to a better looking one
    [Growthline 1_1.fzz, Sample Reading Statistics.xlsx]
2017-06-10 Big changes to base libraries
    The code of the original GrowthLine has been modified and changed in a
    library style. It should be easier to import it to other projects and
    use these libraries to manage sensor readings. There's some work still
    to be done to the Logger file to log information better.
